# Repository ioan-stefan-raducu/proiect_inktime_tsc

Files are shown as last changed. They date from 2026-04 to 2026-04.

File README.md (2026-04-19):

# Proiect TSC 2026 - InkTime

Răducu Ioan Ștefan 335CA

## Descriere proiect
InkTime este un dispozitiv open source de tip smartwatch construit în cadrul clasei de proiectare hardware din UNSTPB. Device-ul are integrat un MCU nRF52840, senzori IMU și un display E-paper într-o carcasă compactă. Designul consideră aspectele legate de consum minim de energie și optimizarea PCB-ului pentru producție.

## Schema bloc
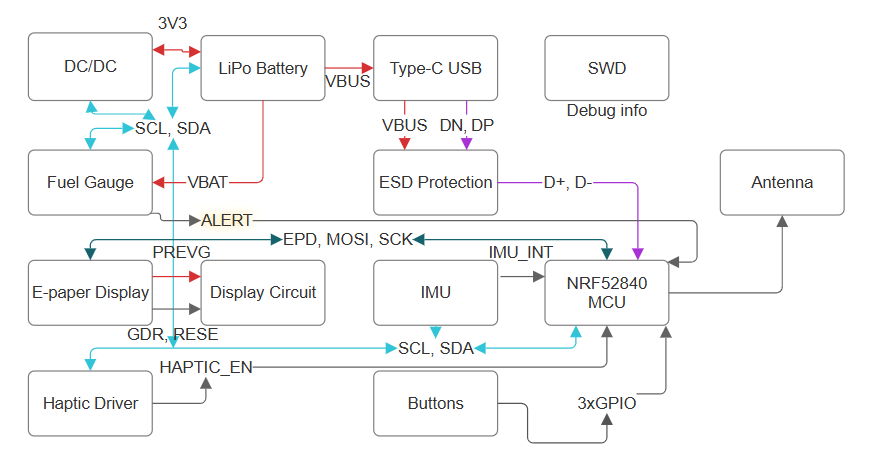
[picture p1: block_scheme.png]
schema bloc


Se pot vedea în schema bloc componentele conectate prin săgeți. Săgețile au următoarele semnificații:
- **roșu** - trasee de putere
- **albastru deschis** - conexiuni I2C
- **albastru închis** - conexiuni SPI
- **mov** - trasee diferențiale
- **gri** - conexiuni GPIO sau fără a aparține categoriilor de mai sus

## Bill of Materials

| Componentă / Valoare | Cant. | Capsulă | Producător / Part Number | Sursă Achiziție (JLC/Mouser) | Datasheet |
| :--- | :---: | :--- | :--- | :--- | :--- |
| **nRF52840** | 1 | aQFN-73 | Nordic / nRF52840-QIAA | [Mouser Link](https://www.mouser.ro/c/?q=nRF52840) | [Datasheet](https://infocenter.nordicsemi.com/pdf/nRF52840_PS_v1.1.pdf) |
| **BMA423** | 1 | 12-pin LGA | Bosch / BMA423 | [Mouser Link](https://www.mouser.co.uk/ProductDetail/Bosch-Sensortec/BMA423?qs=HXFqYaX1Q2xC%252BSgeGoX3mg%3D%3D) | [Datasheet](https://www.bosch-sensortec.com/media/boschsensortec/downloads/datasheets/bst-bma423-ds004.pdf) |
| **BQ25180YBGR** | 1 | BGA-8 | TI / BQ25180YBGR | [Mouser Link](https://www.mouser.co.uk/ProductDetail/Texas-Instruments/BQ25180YBGR?qs=doiCPypUmgEWjAK%252BJAX6Tw%3D%3D) | [Datasheet](https://www.ti.com/lit/ds/symlink/bq25180.pdf) |
| **MAX17048G+T10** | 1 | TDFN-8 | Analog Devices / MAX17048 | [Mouser Link](https://www.mouser.ro/Search/Refine?Keyword=MAX17048G%2BT10) | [Datasheet](https://datasheets.maximintegrated.com/en/ds/MAX17048-MAX17049.pdf) |
| **DRV2605YZFR** | 1 | BGA-9 | TI / DRV2605YZFR | [Mouser Link](https://www.mouser.ro/Search/Refine?Keyword=DRV2605YZFR) | [Datasheet](https://www.ti.com/lit/ds/symlink/drv2605.pdf) |
| **RT6160AWSC** | 1 | WLCSP-15 | Richtek / RT6160AWSC | [Mouser Link](https://www.mouser.co.uk/ProductDetail/Richtek/RT6160AWSC?qs=amGC7iS6iy%2FLd9PSoixZXQ%3D%3D) | [Datasheet](https://www.richtek.com/assets/product_file/RT6160/DS6160-03.pdf) |
| **2450AT18B100E** | 1 | 3216 (1206) | Johanson / Antenă 2.45GHz | [Mouser Link](https://www.mouser.co.uk/ProductDetail/Johanson-Technology/2450AT18B100E?qs=yCnrNFeXz%252Bh5MFsFIXGZGA%3D%3D) | [Datasheet](https://www.johansontechnology.com/datasheets/2450AT18B100E/2450AT18B100E.pdf) |
| **744043680 (L4)** | 1 | 4.8x4.8mm | Wurth / 68µH Inductor | [JLC Part](https://jlcpcb.com/partdetail/Wurth_Elektronik-744043680/C167448) | [Datasheet](https://www.we-online.com/catalog/datasheet/744043680.pdf) |
| **FTC252012SR47** | 1 | 2520 (1008) | TDK / 0.47µH Inductor | [JLC Part (C5832368)](https://jlcpcb.com/partdetail/6763488-FTC252012SR47MBCA/C5832368) | [Datasheet](https://product.tdk.com/en/system/files/dam/doc/product/inductor/inductor/smd/catalog/inductor_commercial_power_ftc252012s_en.pdf) |
| **503480-2400** | 1 | FPC-24 | Molex / Conector EPD | [Mouser Link](https://www.mouser.co.uk/ProductDetail/Molex/503480-2400?qs=OAhjpuo3Vu7efIoxFh9AOw%3D%3D) | [Datasheet](https://www.molex.com/pdm_docs/sd/5034802400_sd.pdf) |
| **USB-C 16P** | 1 | SMT | Kinghelm / KH-TYPE-C-16P | [JLC Part](https://jlcpcb.com/partdetail/Kinghelm-KH_TYPE_C_16P/C5186522) | [Datasheet](https://datasheet.lcsc.com/lcsc/2112151030_Kinghelm-KH-TYPE-C-16P_C2930266.pdf) |
| **EVP-AKE31A** | 3 | SMT (Buton) | Panasonic / Tactile SW | [Mouser Link](https://www.mouser.ro/Search/Refine?Keyword=EVP-AKE31A) | [Datasheet](https://industrial.panasonic.com/ww/products/pt/tactile-sw/models/EVPAKE31A) |
| **USBLC6-2SC6Y** | 1 | SOT-23-6 | ST / Protecție ESD | [JLC Part](https://jlcpcb.com/partdetail/STMicroelectronics-USBLC6_2SC6Y/C7519) | [Datasheet](https://www.st.com/resource/en/datasheet/usblc6-2.pdf) |
| **MBR0530** | 3 | SOD-123 | ON Semi / Schottky 0.5A | [JLC Part](https://jlcpcb.com/partdetail/onsemi-MBR0530T1G/C2131) | [Datasheet](https://www.onsemi.com/pdf/datasheet/mbr0530t1-d.pdf) |
| **SI1308EDL** | 1 | SC-70-3 | Vishay / N-Ch MOSFET | [Mouser Link](https://www.mouser.ro/Search/Refine?Keyword=SI1308EDL) | [Datasheet](https://www.vishay.com/docs/72013/si1308edl.pdf) |
| **DMG2305UX-7** | 1 | SOT-23 | Diodes Inc / P-Ch MOSFET | [JLC Part](https://jlcpcb.com/partdetail/Diodes_Incorporated-DMG2305UX_7/C128526) | [Datasheet](https://www.diodes.com/assets/Datasheets/DMG2305UX.pdf) |

### Rezistente si condensatoare

| Valoare | Cant. | Capsulă | Tip | JLC |
| :--- | :---: | :--- | :--- | :--- |
| **1uF / 50V** | 10 | 0402 | Condensator (EPD) | [C52923](https://jlcpcb.com/partdetail/Samsung_Electro_Mechanics-CL05A105KB5NQNC/C52923) |
| **10uF** | 4 | 0402 | Condensator | [C15525](https://jlcpcb.com/partdetail/Samsung_Electro_Mechanics-CL05A106MQ5NUNC/C15525) |
| **100nF** | 5 | 0201 | Condensator | [C1619](https://jlcpcb.com/partdetail/Murata_Electronics-GRM033R61A104KE84D/C1619) |
| **10K** | 6 | 0201 | Rezistență | [C25744](https://jlcpcb.com/partdetail/Yageo-RC0201JR_0710KL/C25744) |
| **5.1K (5K1)** | 2 | 0201 | Rezistență (USB CC) | [C25785](https://jlcpcb.com/partdetail/Yageo-RC0201JR_075K1L/C25785) |
| **3.3K (3K3)** | 2 | 0201 | Rezistență | [C25891](https://jlcpcb.com/partdetail/Yageo-RC0201JR_073K3L/C25891) |

## Funcționalități hardware

Pentru următoarele funcționalități hardware se vor folosi numele circuitelor așa cum sunt reprezentate în schematic. La conectarea cu alte circuite se vor menționa circuitele cu semnalele puse în paranteză, lângă menționarea lor.

### LiPo Battery
Circuitul LiPo battery este conectorul către baterie. El este amplasat aproape de circuitul **DC/DC (VREG, 3V3)** și **Fuel Gauge (3V3, VBAT)**, formând un ansamblu. Acest ansamblu este amplasat lângă **E-Paper Connector** și **USB Connector (VBUS)** pentru a izola zonele care se ocupă cu traseele de putere sau au putere mare de restul componentelor, pentru a evita interferențele. Este conectat la microcontroler prin protocolul I2C.

### Fuel Gauge
Circuitul Fuel Gauge se ocupă cu măsurarea nivelului bateriei și alertarea microprocesorului când bateria este descărcată. El este conectat la microcontroler prin protocolul I2C și semnalul **ALERT** (probabil folosit ca întrerupere).

### DC/DC
Circuitul DC/DC este adaptorul de tensiune al PCB-ului. El trimite semnale de putere folosind PWM pentru a regla tensiunea. Este conectat la procesor prin protocolul I2C.

### E-Paper Connector
Circuitul E-Paper Connector este conexiunea la ecranul E-Paper. El este conectat la microcontroler prin protocolul SPI. Semnalele care sunt conectate la microcontroler sunt **EPD_BUSY, EPD_RST, EPD_DC, EPD_CS, SCK și MOSI**. El este conectat și la circuitul **E-Paper Drive Circuit** prin PREVGH, PREVGL și 3V3.

### E-Paper Drive Circuit
Circuitul E-Paper Drive "crește” semnalul pentru modelarea cernelii pentru ecranul E-Paper. El este plasat direct lângă **E-Paper Display Connector** datorită semnalului puternic de putere (până la 50V) pe care îl transmite ecranului. Astfel, ansamblul de putere menționat mai devreme, conectorul E-Paper și acest circuit sunt puse apropiat pentru a nu interfera cu restul PCB-ului.

### USB-C Connector
Circuitul USB-C Connector reprezintă mufa USB. Este conectat la ansamblul de putere (VBUS) și la circuitul **ESD Protection (VBUS, DN, DP)**. Deși în designul PCB-ului DN și DP ar trebui să fie trasee diferențiale, ele nu sunt. Am luat această decizie datorită poziției apropiate a USB-C Connector față de circuitul ESD Protection. El este conectat la microcontroler prin semnalul VBUS și indirect, prin ESD Protection, prin semnalele diferențiale D+ și D-.

### ESD Protection
Circuitul ESD Protection reprezintă protecția mufei USB-C în cazul descărcărilor statice. El este conectat la **USB-C Connector (VBUS, DN, DP)** și la microcontroler (D+, D- trasee diferențiale). În designul PCB-ului, semnalele D+ și D- au aceeași lungime.

### SWD
Circuitul SWD este folosit pentru debugging și este conectat la semnalele importante (**RESET, 3V3 și GND**). Poate fi conectat la JTAG.

### Haptic Driver
Circuitul Haptic Driver este cel responsabil de vibrația ceasului. El este conectat la microcontroler prin protocolul I2C și semnalul **HAPTIC_EN**. În PCB, el este situat la distanță de IMU pentru a nu interfera cu acesta în momentul în care vibrează.

### IMU
Circuitul IMU măsoară accelerația și direcția ceasului pentru a determina câți pași a făcut utilizatorul. El este amplasat departe de Haptic Driver pentru motivul menționat mai sus și spre centrul ceasului pentru a măsura cât mai precis pașii (mișcarea ceasului pe mână poate afecta măsurătorile). El este conectat la microcontroler prin I2C și semnalele **IMUINT1 și IMUINT2** (întreruperi ce pot fi setate).

## Descrierea conexiunilor microcontrolerului nRF52840

* **P$AD22 (SWO)** - conexiune cu TP_SWO pentru debug.
* **P$AC13 (RESET)** - conexiune cu TP_RESET și SWD pentru resetarea componentei.
* **P$AD12 (EPD_BUSY)** - conexiune cu E-Paper Display (EPD_BUSY). Indică dacă ecranul este ocupat cu afișarea sau nu.
* **P$AD10 (EPD_DC)** - conexiune cu E-Paper Display (EPD_DC - Data/Command). Descrie dacă bitul trimis este pentru date (pixeli) sau o comandă.
* **P$K2 (EPD_CS)** - conexiune cu E-Paper Display (EPD_CS - Chip Select) pentru protocolul SPI.
* **P$AD12 (EPD_RST)** - conexiune cu E-Paper Display (EPD_RST) pentru resetare.
* **P$AC9 (P0.14)** - GPIO buton din mijloc.
* **P$AD8 (P0.13)** - GPIO buton din dreapta.
* **P$W24 (P1.02)** - GPIO buton din stânga.
* **P$AD6 (D+)** - traseu diferențial pozitiv către ESD Protection.
* **P$AD4 (D-)** - traseu diferențial negativ către ESD Protection.
* **P$AD2 (VBUS)** - conexiune cu semnalul VBUS al USB-C Connector.
* **P$U1 (HAPTIC_EN)** - conexiune cu Haptic Driver pentru enable/disable.
* **P$T2 (PMIC_INT)** - conexiune întrerupere cu circuitul bateriei (LiPo Battery).
* **P$P2 (IMU_INT2)** - conexiune întrerupere cu IMU.
* **P$M2 (SCL)** - conexiune I2C între restul componentelor care folosesc acest protocol.
* **P$N1 (IMU_INT1)** - conexiune întrerupere cu IMU.
* **P$L1 (SDA)** - conexiune I2C cu restul componentelor care folosesc acest protocol.
* **P$F2 și P$D2** - conexiune cu ceasul de 32 kHz.
* **P$A12 (SCK)** - conexiune clock cu ecranul pentru protocolul SPI.
* **P$P13 (MOSI)** - MOSI pentru conexiunea SPI (cu ecranul).
* **P$A23 și P$A24** - conexiune cu ceasul de 32 MHz.
* **P$J24 (ALERT)** - conexiune cu alerta circuitului Fuel Gauge.
* **P$Y23 (P1.01)** - conexiune care conduce E-Paper Drive Circuit pentru a afișa cerneala pe ecran.
* **P$AA24 (SWDCLK)** - conexiune pentru SWD, cu scopul de debug al ceasului.
* **P$AC24 (SWDIO)** - conexiune SWD input/output.
* **P$H23, P$F23** - conexiune pentru transmiterea wireless prin antenă.

## Aprobarea erorilor și alte detalii

În afara erorilor de overlap deja aprobate la început (în total 6 erori), restul erorilor pot fi explicate astfel:
* **6 erori** de Solid Polygon Shape, Overlap, la butoane, apărute de la sincronizarea inițială a schematicului cu PCB-ul.
* **11 erori** de Via-SMD sau SMD-Via, Overlap, pentru via-in-pad a pinilor de pe procesor.

### Detalii post-review
* Am mutat circuitul **IMU** mai sus pentru a aloca suficient spațiu pe PCB pentru un via mai gros de la pinul 3V3 la stratul POWER. Pre-review se folosea un via cu grosimea de 0.2mm direct sub componenta IMU.
* Pentru a rezolva al doilea via cu grosimea de 0.2mm pentru un traseu de putere de la pinul P$AD23 al nRF52840, am alocat suficient spațiu pentru a avea grosimea indicată.
* La rezolvarea greșelii din schematic în care am folosit componenta **NORDIC_NRF_3_CAPACITOR** în locul componentei **GRM011R60J152KE01L** pentru condensatori, a apărut problema overlap cu fire de 0.3mm din cauza footprint-ului 0201 pe care îl are obligatoriu noua componentă. Pentru a rezolva, am variat grosimea la 0.25mm. Personal aș fi păstrat componenta precedentă datorită footprint-ului 0402.
* Am mutat firul **P0.14** de pe bottom pentru a nu trece sub ceasul de 32 kHz al procesorului.
* În urma modificării schematicului circuitului Haptic Driver, pinul **SDA** era plasat în mijloc. Pentru a rezolva problema, am folosit via-in-pad. De asemenea, a fost nevoie să conectez pinul GND și am folosit via către stratul GND.

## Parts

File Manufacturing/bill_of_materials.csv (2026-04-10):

Qty | Value | Device | Package | Parts | Description | ARROW_PART_NUMBER | ARROW_PRICE-STOCK | AVAILABILITY | CHECK_PRICES | COPYRIGHT | DESCRIPTION | DIGI-KEY_PART_NUMBER_1 | DIGI-KEY_PART_NUMBER_2 | DIGI-KEY_PART_NUMBER_3 | HEIGHT | JLCPCB | MANUFACTURER_NAME | MANUFACTURER_PART_NUMBER | MF | MFR_NAME | MOUSER_PART_NUMBER | MOUSER_PRICE-STOCK | MP | PACKAGE | POPULARITY | PRICE | PROD_ID | PURCHASE-URL | SNAPEDA_LINK | TP_SIGNAL_NAME | VALUE
3 | 0 | CPF0201D7K68C1_CPF0201D7K68C1 | CPF0201D7K68C1_0201 | R2, R3, R4 | 7.68k 0201 Thin Film Surface Mount Fixed Resistor +/-0.5% 0.031W CPF0201D7K68C1
4 | 0.1uF | NORDIC_NRF_3_CAPACITOR_0201_L | NORDIC_NRF_3_RESC0201_L | C23, C27, C34, C42 | Generic chip capacitor
1 | 0.47 | CPF0201D7K68C1_CPF0201D7K68C1 | CPF0201D7K68C1_0201 | R1_EP_DR | 7.68k 0201 Thin Film Surface Mount Fixed Resistor +/-0.5% 0.031W CPF0201D7K68C1
5 | 100nF | NORDIC_NRF_3_CAPACITOR_0201_L | NORDIC_NRF_3_RESC0201_L | C5, C7, C8, C12, C19 | Generic chip capacitor
1 | 100pF | NORDIC_NRF_3_CAPACITOR_0201_L | NORDIC_NRF_3_RESC0201_L | C11 | Generic chip capacitor
6 | 10K | CPF0201D7K68C1_CPF0201D7K68C1 | CPF0201D7K68C1_0201 | R2_EP_DR, R5, R7, R8, R9, R_PWR_EPD | 7.68k 0201 Thin Film Surface Mount Fixed Resistor +/-0.5% 0.031W CPF0201D7K68C1
4 | 10uF | NORDIC_NRF_3_CAPACITOR_0402_L | NORDIC_NRF_3_RESC0402_L | C1-EP-DR, C1-EP-DR1, C24, C39 | Generic chip capacitor
1 | 10uH | NORDIC_NRF_2_INDUCTOR_0402_L | NORDIC_NRF_2_RESC0402_L | L2 | Generic chip inductor
4 | 12pF | NORDIC_NRF_3_CAPACITOR_0201_L | NORDIC_NRF_3_RESC0201_L | C1, C2, C17, C18 | Generic chip capacitor
1 | 15nH | NORDIC_NRF_2_INDUCTOR_0201_L | NORDIC_NRF_2_RESC0201_L | L3 | Generic chip inductor
2 | 1pF | NORDIC_NRF_3_CAPACITOR_0201_L | NORDIC_NRF_3_RESC0201_L | C3, C4 | Generic chip capacitor
7 | 1uF | NORDIC_NRF_3_CAPACITOR_0402_L | NORDIC_NRF_3_RESC0402_L | C15, C29, C30, C31, C32, C37, C38 | Generic chip capacitor
10 | 1uF/50V | NORDIC_NRF_3_CAPACITOR_0402_L | NORDIC_NRF_3_RESC0402_L | EPD_C1, EPD_C2, EPD_C5, EPD_C6, EPD_C7, EPD_C8, EPD_C9, EPD_C10, EPD_C11, EPD_C12 | Generic chip capacitor
1 | 2.2 | CPF0201D7K68C1_CPF0201D7K68C1 | CPF0201D7K68C1_0201 | R_TYPE_SEL | 7.68k 0201 Thin Film Surface Mount Fixed Resistor +/-0.5% 0.031W CPF0201D7K68C1
3 | 2025-10-22_07-23-44_LIBRARY_EVP-AKE31ASW_EVP-AKE31A_PAN | 2025-10-22_07-23-44_LIBRARY_EVP-AKE31ASW_EVP-AKE31A_PAN | 2025-10-22_07-23-44_LIBRARY_SW_EVP-AKE31A_PAN | SW_DN, SW_ENT, SW_UP |  |  |  |  |  | Copyright (C) 2025 Ultra Librarian. All rights reserved. |  | P123437TR-ND | P123437CT-ND | P123437DKR-ND |  |  | Panasonic | EVP-AKE31A
1 | 20V/4.2A/52mO/1.4W | ESP32_C6_LIBRARY_4_ESP32_WROVER_SPARKFUN-DISCRETESEMI_MOSFET_PCH-DMG2305UX-7 | ESP32_C6_LIBRARY_4_ESP32_C6_LIBRARY_4_ESP32_C6_LIBRARY_4_ESP32_C6_LIBRARY_4_ESP32_WROVER_SPARKFUN-DISCRETESEMI_SOT23-3 | Q1 | P-channel MOSFETs |  |  |  |  |  |  |  |  |  |  |  |  |  |  |  |  |  |  |  |  |  | TRAN-14388 |  |  |  | 20V/4.2A/52mO/1.4W
2 | 22uF | NORDIC_NRF_3_CAPACITOR_0402_L | NORDIC_NRF_3_RESC0402_L | C25, C33 | Generic chip capacitor
1 | 2450AT18B100E | 2450AT18B100E_2450AT18B100E | 2450AT18B100E_ANTC3216X140N | ANT1 | Antennas 2.45GHz ANTENNA | 2450AT18B100E | https://www.arrow.com/en/products/2450at18b100e/johanson-dielectrics?utm_currency=USD&region=nac |  |  |  | Antennas 2.45GHz ANTENNA |  |  |  | 1.4mm |  | JOHANSON TECHNOLOGY | 2450AT18B100E |  |  | 609-2450AT18B100E | https://www.mouser.co.uk/ProductDetail/Johanson-Technology/2450AT18B100E?qs=yCnrNFeXz%252Bh5MFsFIXGZGA%3D%3D
1 | 3.9nH | NORDIC_NRF_2_INDUCTOR_0201_L | NORDIC_NRF_2_RESC0201_L | L1 | Generic chip inductor
1 | 32.768kHz | NORDIC_NRF_1_XTAL_32KHZ | NORDIC_NRF_1_XTAL_3215_N | X2
1 | 32MHz | NORDIC_NRF_XTAL_32MHZ | NORDIC_NRF_BT-XTAL_2016_N | X1
2 | 3K3 | CPF0201D7K68C1_CPF0201D7K68C1 | CPF0201D7K68C1_0201 | R17, R18 | 7.68k 0201 Thin Film Surface Mount Fixed Resistor +/-0.5% 0.031W CPF0201D7K68C1
5 | 4.7uF | NORDIC_NRF_3_CAPACITOR_0402_L | NORDIC_NRF_3_RESC0402_L | C6, C14, C20, C21, C43 | Generic chip capacitor
1 | 47nF | NORDIC_NRF_3_CAPACITOR_0201_L | NORDIC_NRF_3_RESC0201_L | C16 | Generic chip capacitor
1 | 503480-2400 | 503480-2400_503480-2400 | 503480-2400_5034802400 | J1 | FFC & FPC Connectors 0.5mm FPC RA SMT Dual Contact 24Ckt |  |  |  |  |  | FFC & FPC Connectors 0.5mm FPC RA SMT Dual Contact 24Ckt |  |  |  | 1.87mm |  | Molex | 503480-2400 |  |  | 538-503480-2400 | https://www.mouser.co.uk/ProductDetail/Molex/503480-2400?qs=OAhjpuo3Vu7efIoxFh9AOw%3D%3D
2 | 5K1 | ERA-1AEB3401C_CPF0201D7K68C1 | ERA-1AEB3401C_0201 | R1_USB, R2_USB | 7.68k 0201 Thin Film Surface Mount Fixed Resistor +/-0.5% 0.031W CPF0201D7K68C1
1 | 68uH | ESP32_C6_LIBRARY_2_744043680IND_4828-WE-TPC_WRE | ESP32_C6_LIBRARY_2_IND_4828-WE-TPC_WRE | L4 |  |  |  |  |  | Copyright (C) 2024 Ultra Librarian. All rights reserved. |  |  |  |  |  |  |  | 744043680 |  | Wurth Electronics
1 | 820pF | NORDIC_NRF_3_CAPACITOR_0201_L | NORDIC_NRF_3_RESC0201_L | C9 | Generic chip capacitor
1 | BMA423 | BMA423_BMA423 | BMA423_BMA423 | IC3 | Accelerometers Triaxial low-g 12bit Acceleration Sensor | BMA423 | https://www.arrow.com/en/products/bma423/bosch |  |  |  | Accelerometers Triaxial low-g 12bit Acceleration Sensor |  |  |  | 1mm |  | BOSCH | BMA423 |  |  | 262-BMA423 | https://www.mouser.co.uk/ProductDetail/Bosch-Sensortec/BMA423?qs=HXFqYaX1Q2xC%252BSgeGoX3mg%3D%3D
1 | BQ25180YBGR | BQ25180YBGR_BQ25180YBGR | BQ25180YBGR_BGA8C40P2X4_100X155X50 | IC1 | Charger IC Lithium Ion/Polymer, Lithium Iron Phosphate 8-DSBGA (1.6x1.1) | BQ25180YBGR | https://www.arrow.com/en/products/bq25180ybgr/texas-instruments?utm_currency=USD&region=nac |  |  |  | Charger IC Lithium Ion/Polymer | Lithium Iron Phosphate 8-DSBGA (1.6x1.1) |  |  |  | 0.5mm |  | Texas Instruments | BQ25180YBGR |  |  | 595-BQ25180YBGR | https://www.mouser.co.uk/ProductDetail/Texas-Instruments/BQ25180YBGR?qs=doiCPypUmgEWjAK%252BJAX6Tw%3D%3D
1 | DRV2605YZFR | DRV2605YZFR_DRV2605YZFR | DRV2605YZFR_BGA9C50P3X3_144X144X62 | IC2 | Haptic Driver for ERM/LRA with Built-In Library and Smart Loop Architecture | DRV2605YZFR | https://www.arrow.com/en/products/drv2605yzfr/texas-instruments?region=nac |  |  |  | Haptic Driver for ERM/LRA with Built-In Library and Smart Loop Architecture |  |  |  | 0.625mm |  | Texas Instruments | DRV2605YZFR
1 | FTC252012SR47MBCA | MLP2016SR47MT0S1_FTC252012SR47MBCA | MLP2016SR47MT0S1_INDC2016X100N | L7 | SMD / SMT Inductors (Coils), L=0.47?H, L x W x T : |  |  |  |  |  | SMD / SMT Inductors (Coils) | L=0.47?H | L x W x T : |  |  |  | 1mm | https://jlcpcb.com/partdetail/6763488-FTC252012SR47MBCA/C5832368 | TDK | FTC252012SR47MBCA
14 | HECTOR_WATCH_1_TPTP20R | HECTOR_WATCH_1_TPTP20R | HECTOR_WATCH_1_TP20R | TP_3.3V, TP_3V3, TP_BAT_GND, TP_GND, TP_ON, TP_OP, TP_RESET\, TP_SCL, TP_SDA, TP_SWDCLK, TP_SWDIO, TP_SWO, TP_VBAT, TP_VREG | Test pad |  |  |  |  |  |  |  |  |  |  |  |  |  |  |  |  |  |  |  | 2
1 | JUMPER_SJ | ESP32_C6_LIBRARY_7_JUMPER_SJ | ESP32_C6_LIBRARY_7_JUMPER_SJ | SJ1 | SMD solder JUMPER |  |  |  |  |  |  |  |  |  |  |  |  |  |  |  |  |  |  |  | 3
1 | KH-TYPE-C-16P | KH-TYPE-C-16P_KH-TYPE-C-16P | KH-TYPE-C-16P_KINGHELM_KH-TYPE-C-16P | J4 | Check availability |  |  | Not in stock | https://www.snapeda.com/parts/KH-TYPE-C-16P/Kinghelm/view-part/?ref=eda |  |  |  |  |  |  |  |  |  | kinghelm |  |  |  | KH-TYPE-C-16P | None |  | None |  |  | https://www.snapeda.com/parts/KH-TYPE-C-16P/Kinghelm/view-part/?ref=snap
1 | MAX17048G+T10 | ESP32_C6_LIBRARY_MAX17048G+T10 | ESP32_C6_LIBRARY_SON50P200X200X80-9N | U3 | Check availability |  |  | In Stock | https://www.snapeda.com/parts/MAX17048G+T10/Analog+Devices/view-part/?ref=eda |  | 3µA 1-Cell/2-Cell Fuel Gauge with ModelGauge |  |  |  |  |  |  |  | Analog Devices |  |  |  | MAX17048G+T10 | TDFN-8 Maxim |  | None |  | https://www.snapeda.com/api/url_track_click_mouser/?unipart_id=329239&manufacturer=Analog Devices&part_name=MAX17048G+T10&search_term=None | https://www.snapeda.com/parts/MAX17048G+T10/Analog+Devices/view-part/?ref=snap
3 | MBR0530 | ESP32_C6_LIBRARY_5_MBR0530 | ESP32_C6_LIBRARY_5_SOD3716X135N | D3, D4, D5 | ON SEMICONDUCTOR - MBR0530 - DIODE, SCHOTTKY, 0.5A, 30V, SOD-123 |  |  | In Stock | https://www.snapeda.com/parts/MBR0530/Onsemi/view-part/?ref=eda |  | Diode Schottky 30 V 500mA Surface Mount SOD-123 |  |  |  |  |  |  |  | ON Semiconductor |  |  |  | MBR0530 | SOD-123-2 ON Semiconductor |  | None |  | https://www.snapeda.com/api/url_track_click_mouser/?unipart_id=179458&manufacturer=ON Semiconductor&part_name=MBR0530&search_term=None | https://www.snapeda.com/parts/MBR0530/Onsemi/view-part/?ref=snap
3 | N.C. | NORDIC_NRF_3_CAPACITOR_0201_L | NORDIC_NRF_3_RESC0201_L | C10, C13, C22 | Generic chip capacitor
1 | NRF52840_QF | NORDIC_NRF_4_NRF52840_QF | NORDIC_NRF_4_AQFN50P700X700X85_HS-74N | U1 | nRF52840
1 | RT6160AWSC | RT6160AWSC_RT6160AWSC | RT6160AWSC_BGA15C40P3X5_140X230X60 | IC9 | Buck-Boost Regulator Positive Output Step-Up/Step-Down I2C DC-DC Controller IC 15-WL-CSP (BSC) (1.4x2.3) |  |  |  |  |  | Buck-Boost Regulator Positive Output Step-Up/Step-Down I2C DC-DC Controller IC 15-WL-CSP (BSC) (1.4x2.3) |  |  |  | 0.6mm |  | RICHTEK | RT6160AWSC |  |  | 835-RT6160AWSC | https://www.mouser.co.uk/ProductDetail/Richtek/RT6160AWSC?qs=amGC7iS6iy%2FLd9PSoixZXQ%3D%3D
1 | SI1308EDL-T1-GE3 | ESP32_C6_LIBRARY_6_SI1308EDL-T1-GE3 | ESP32_C6_LIBRARY_6_SOT65P210X110-3N | Q3 | MOSFET N-Ch 30V 1.5A TrenchFET SC70 Vishay Si1308EDL-T1-GE3 N-channel MOSFET Transistor, 1.5 A, 30 V, 3-Pin SC-70 |  |  | In Stock | https://www.snapeda.com/parts/SI1308EDL-T1-GE3/Vishay+Siliconix/view-part/?ref=eda |  | Si1308EDL-T1-GE3 N-channel MOSFET Transistor | 1.5 A | 30 V | 3-Pin SC-70 | Siliconix / Vishay SI1308EDL-T1-GE3 |  |  |  |  |  |  |  | Vishay Siliconix |  |  |  | SI1308EDL-T1-GE3 | SOT-323 Vishay Semiconductor |  | None |  | https://www.snapeda.com/api/url_track_click_mouser/?unipart_id=274603&manufacturer=Vishay Siliconix&part_name=SI1308EDL-T1-GE3&search_term=None
1 | TC2030-IDC | TC2030-IDC_TC2030-IDC | TC2030-IDC_TC2030IDC | J2 | CABLE ADAPTER 6 POS |  |  |  |  |  | CABLE ADAPTER 6 POS |  |  |  | 19mm |  | Tag Connect | TC2030-IDC
1 | USBLC6-2SC6Y | ESP32_C6_LIBRARY_3_USBLC6-2SC6Y | ESP32_C6_LIBRARY_3_SOT95P280X145-6N | D2 | Low Cap. ESD Protection Auto SOT-23-6 STMicroelectronics USBLC6-2SC6Y, Dual Uni-Directional TVS Diode Array, 6-Pin SOT-23 |  |  | In Stock | https://www.snapeda.com/parts/USBLC6-2SC6Y/STMicroelectronics/view-part/?ref=eda |  | 17V Clamp 5A (8/20µs) Ipp Tvs Diode Surface Mount SOT-23-6 |  |  |  |  |  |  |  | STMicroelectronics |  |  |  | USBLC6-2SC6Y | SOT-23-6 STMicroelectronics |  | None |  |  | https://www.snapeda.com/parts/USBLC6-2SC6Y/STMicroelectronics/view-part/?ref=snap

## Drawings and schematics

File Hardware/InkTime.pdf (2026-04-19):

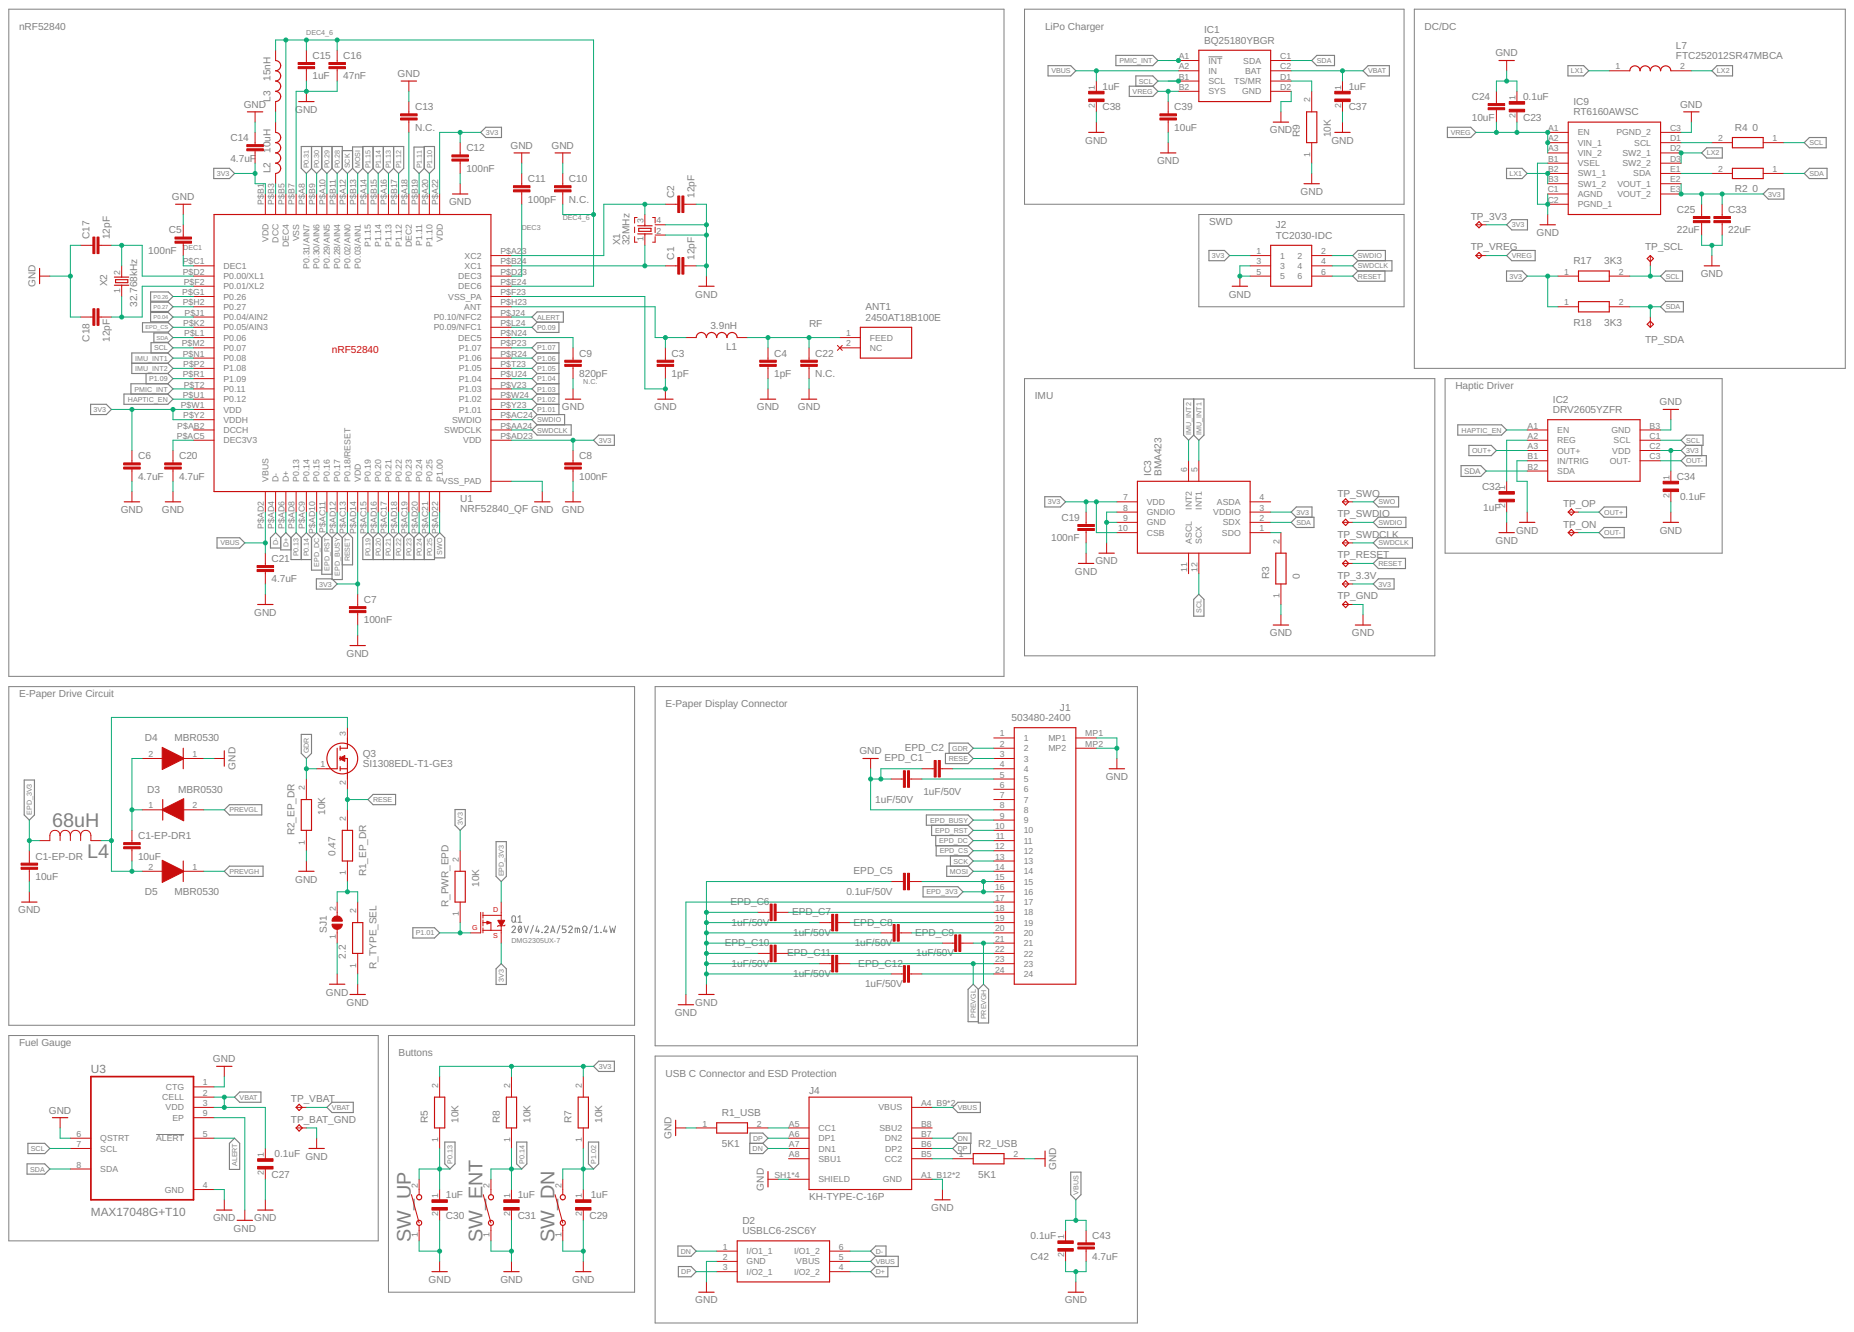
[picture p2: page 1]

10KGND GND GND GND GND

EPD_3V3 | 16

18
19
20

22
23
24

USB C Connector and ESD Protection

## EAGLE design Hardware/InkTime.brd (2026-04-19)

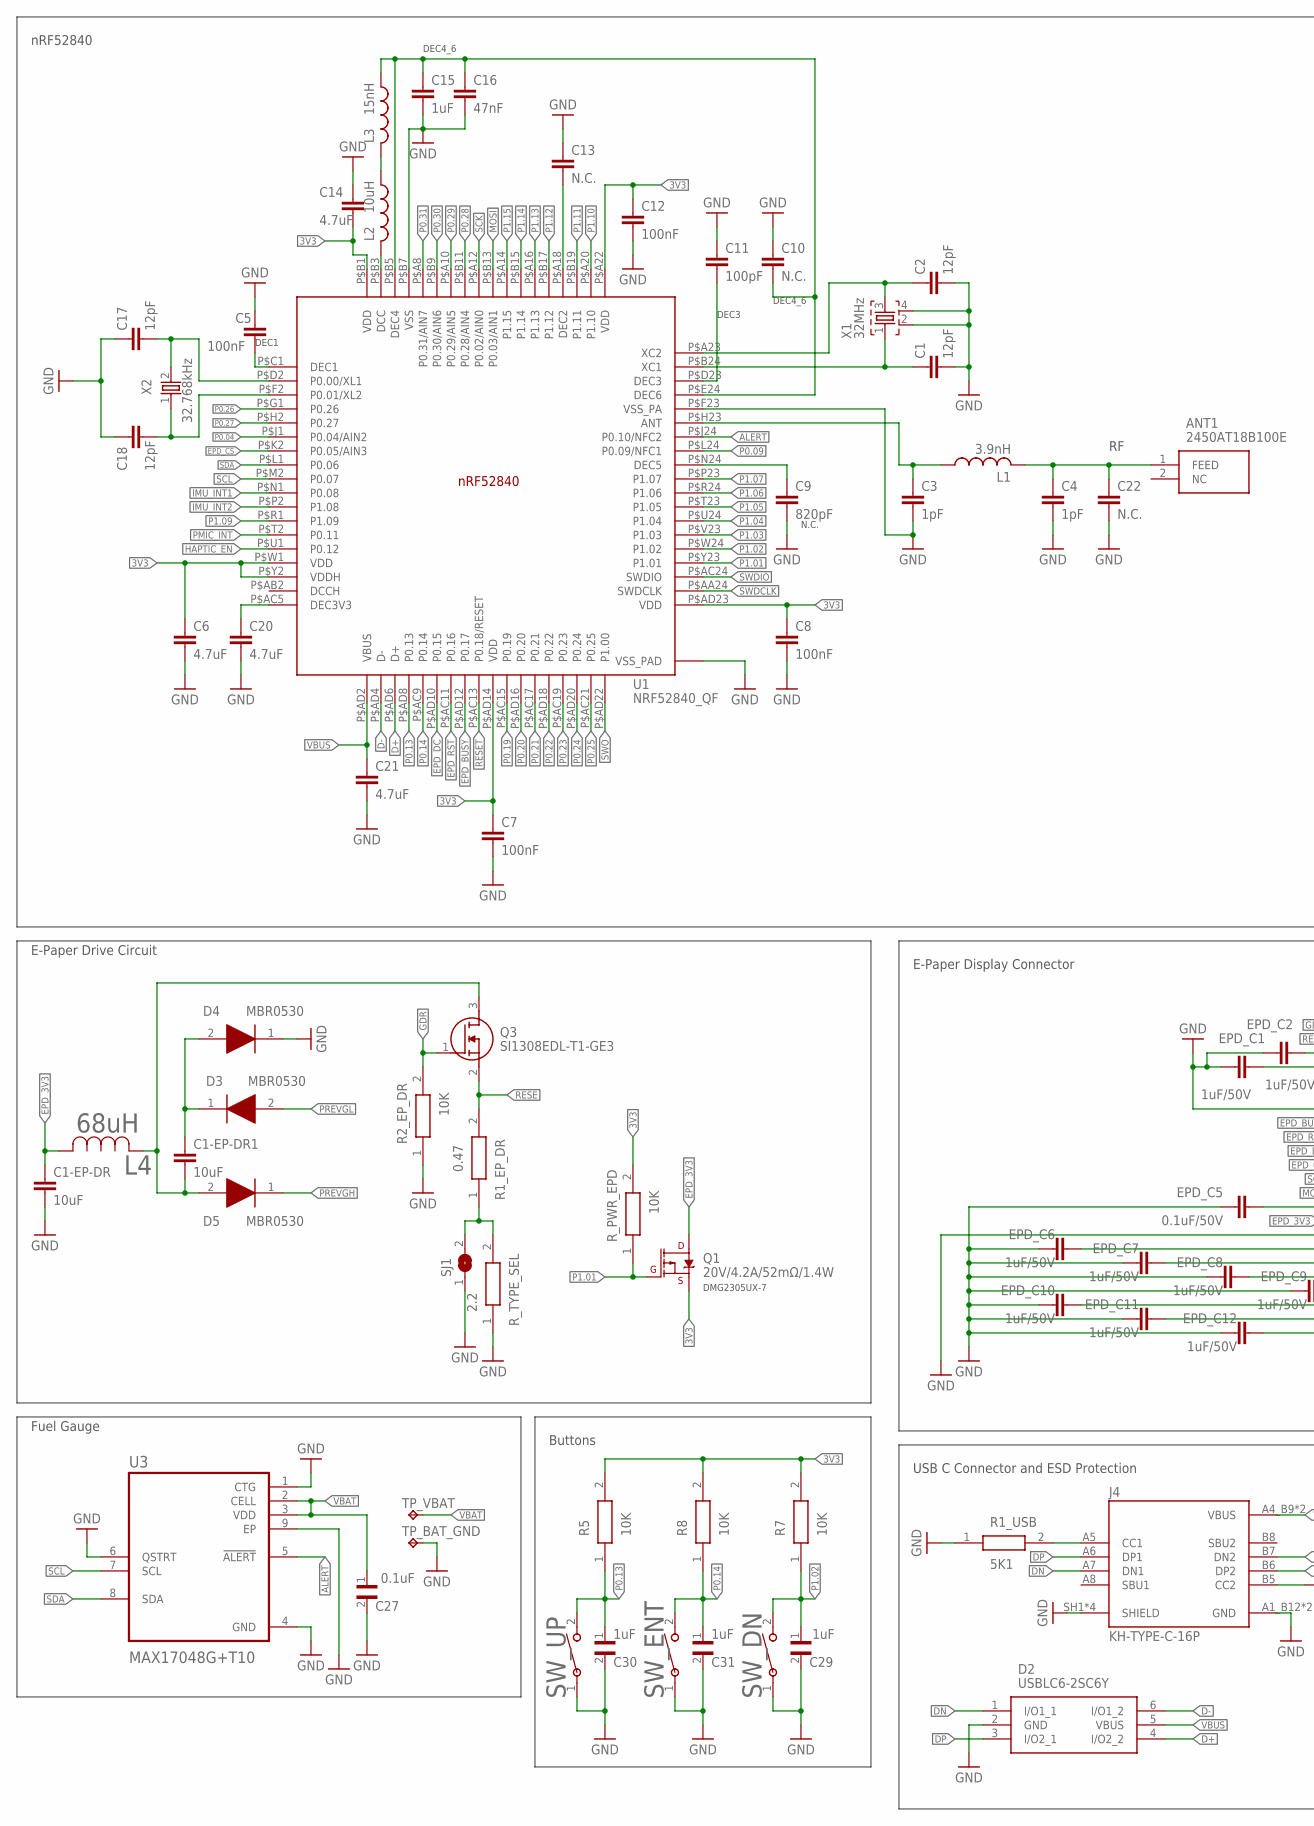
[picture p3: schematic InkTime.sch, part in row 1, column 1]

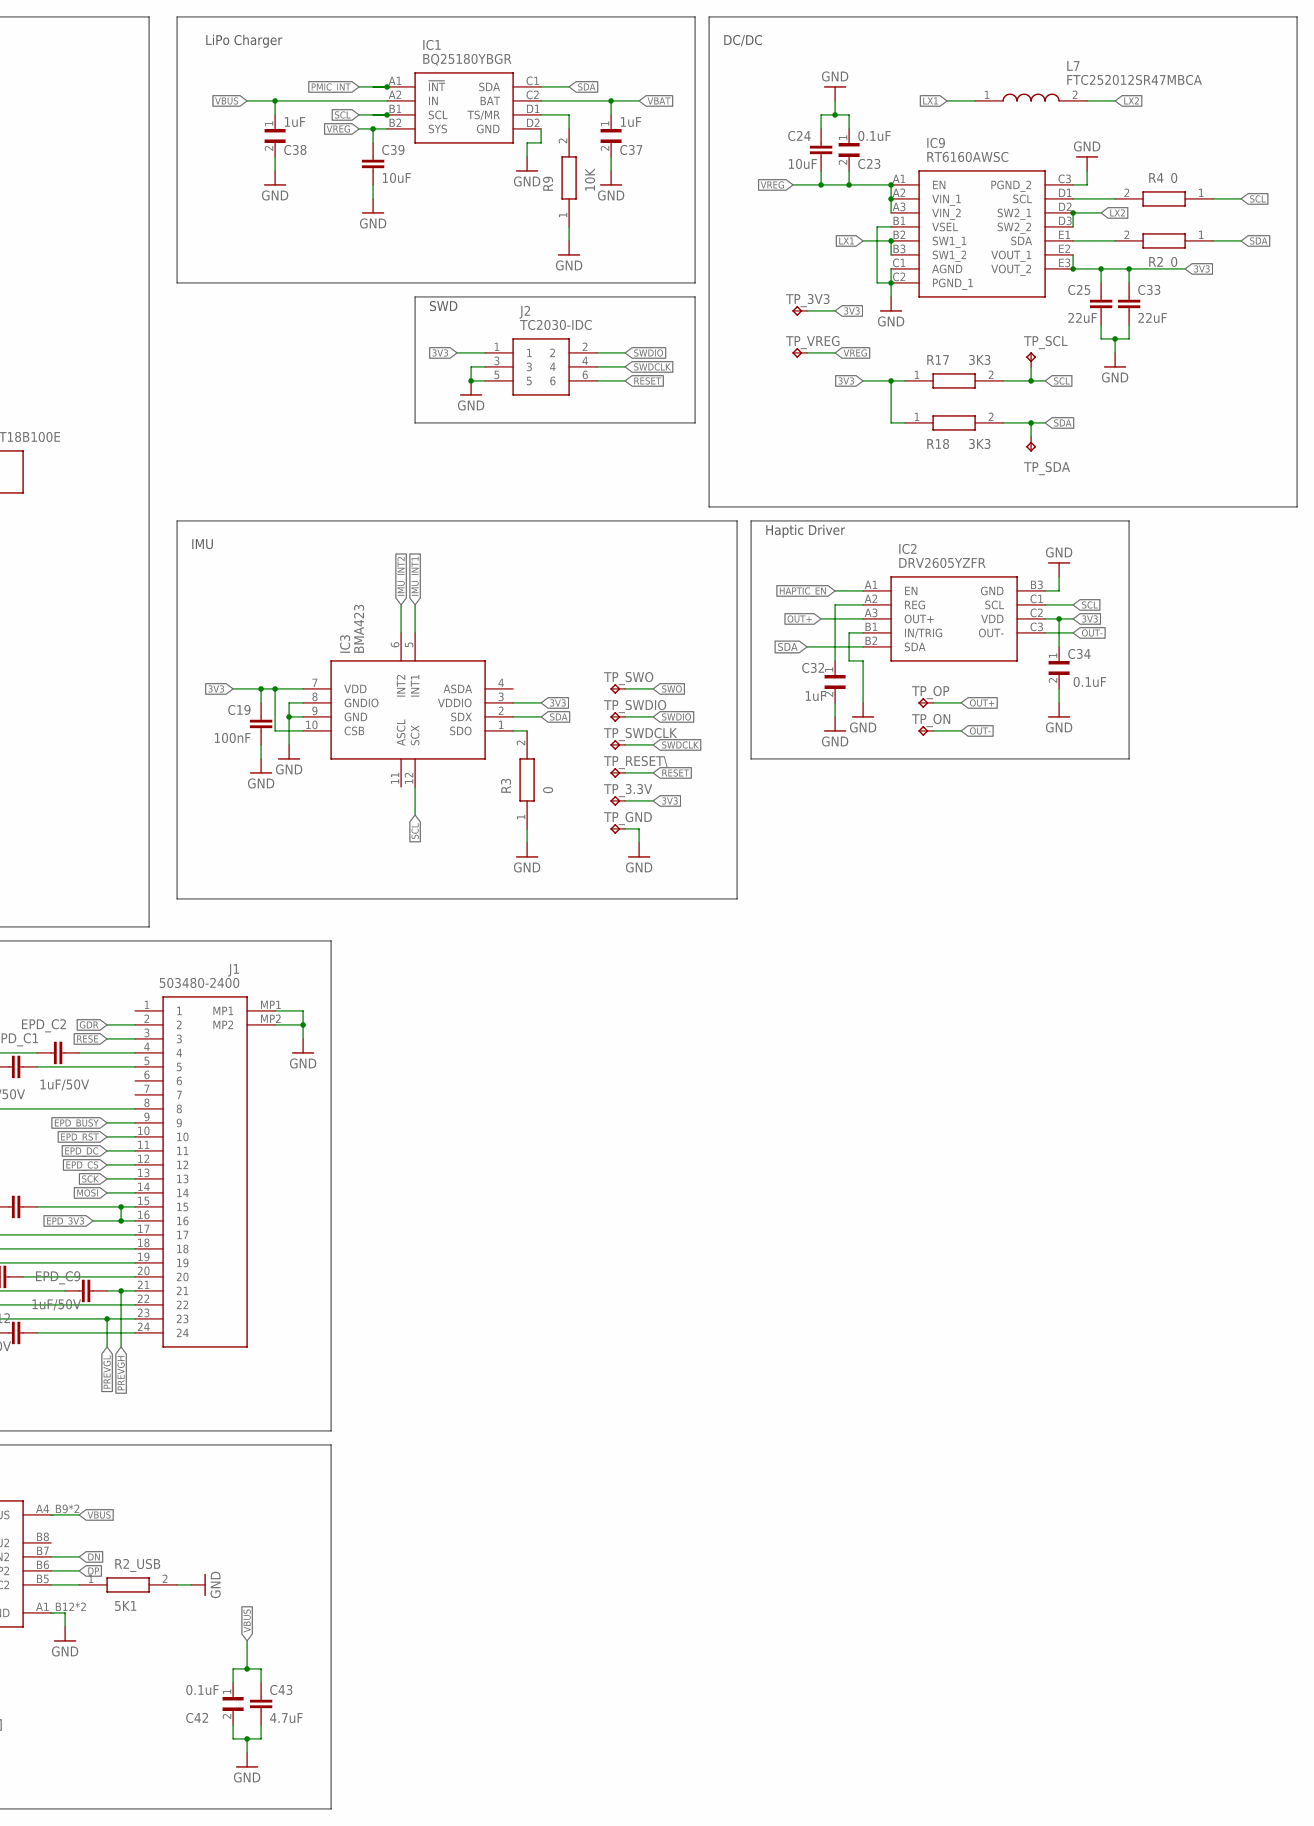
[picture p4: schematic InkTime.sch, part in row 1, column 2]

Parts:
ANT1: 2450AT18B100E; 2450AT18B100E_ANTC3216X140N
C1, C2, C17, C18: 12pF; NORDIC_NRF_3_RESC0201_L
C1-EP-DR, C1-EP-DR1, C24, C39: 10uF; NORDIC_NRF_3_RESC0402_L
C3, C4: 1pF; NORDIC_NRF_3_RESC0201_L
C5, C7, C8, C12, C19: 100nF; NORDIC_NRF_3_RESC0201_L
C6, C14, C20, C21, C43: 4.7uF; NORDIC_NRF_3_RESC0402_L
C9: 820pF; NORDIC_NRF_3_RESC0201_L
C10, C13, C22: N.C.; NORDIC_NRF_3_RESC0201_L
C11: 100pF; NORDIC_NRF_3_RESC0201_L
C15: 1uF; NORDIC_NRF_3_RESC0402_L
C16: 47nF; NORDIC_NRF_3_RESC0201_L
C23, C27, C34, C42: 0.1uF; GRM011R60J152KE01L_2_CAPC0201X13N
C25, C33: 22uF; NORDIC_NRF_3_RESC0402_L
C29, C30, C31, C32, C37, C38: 1uF; GRM011R60J152KE01L_2_CAPC0201X13N
D2: USBLC6-2SC6Y; ESP32_C6_LIBRARY_3_SOT95P280X145-6N
D3, D4, D5: MBR0530; ESP32_C6_LIBRARY_5_SOD3716X135N
EPD_C1, EPD_C2, EPD_C6, EPD_C7, EPD_C8, EPD_C9, EPD_C10, EPD_C11, EPD_C12: 1uF/50V; NORDIC_NRF_3_RESC0402_L
EPD_C5: 0.1uF/50V; NORDIC_NRF_3_RESC0201_L
IC1: BQ25180YBGR; BQ25180YBGR_BGA8C40P2X4_100X155X50
IC2: DRV2605YZFR; DRV2605YZFR_BGA9C50P3X3_144X144X62
IC3: BMA423; BMA423_BMA423
IC9: RT6160AWSC; RT6160AWSC_BGA15C40P3X5_140X230X60
J1: 503480-2400; 503480-2400_5034802400
J2: TC2030-IDC; TC2030-IDC_TC2030IDC
J4: KH-TYPE-C-16P; KH-TYPE-C-16P_KINGHELM_KH-TYPE-C-16P
L1: 3.9nH; NORDIC_NRF_2_RESC0201_L
L2: 10uH; NORDIC_NRF_2_RESC0402_L
L3: 15nH; NORDIC_NRF_2_RESC0201_L
L4: 68uH; ESP32_C6_LIBRARY_2_IND_4828-WE-TPC_WRE
L7: FTC252012SR47MBCA; MLP2016SR47MT0S1_INDC2016X100N
Q1: 20V/4.2A/52mΩ/1.4W; ESP32_C6_LIBRARY_4_ESP32_C6_LIBRARY_4_ESP32_C6_LIBRARY_4_ES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
Q3: SI1308EDL-T1-GE3; ESP32_C6_LIBRARY_6_SOT65P210X110-3N
R1_EP_DR: 0.47; CPF0201D7K68C1_0201
R1_USB, R2_USB: 5K1; ERA-1AEB3401C_0201
R2, R3, R4: 0; CPF0201D7K68C1_0201
R2_EP_DR, R5, R7, R8, R9: 10K; CPF0201D7K68C1_0201
R17, R18: 3K3; CPF0201D7K68C1_0201
R_PWR_EPD: 10K; CPF0201D7K68C1_0201
R_TYPE_SEL: 2.2; CPF0201D7K68C1_0201
SJ1: JUMPER_SJ; ESP32_C6_LIBRARY_7_JUMPER_SJ
SW_DN: 2025-10-22_07-23-44_LIBRARY_EVP-AKE31ASW_EVP-AKE3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; 2025-10-22_07-23-44_LIBRARY_SW_EVP-AKE31A_PAN
SW_ENT: 2025-10-22_07-23-44_LIBRARY_EVP-AKE31ASW_EVP-AKE3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; 2025-10-22_07-23-44_LIBRARY_SW_EVP-AKE31A_PAN
SW_UP: 2025-10-22_07-23-44_LIBRARY_EVP-AKE31ASW_EVP-AKE3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; 2025-10-22_07-23-44_LIBRARY_SW_EVP-AKE31A_PAN
TP_3.3V, TP_3V3: HECTOR_WATCH_1_TPTP20R; HECTOR_WATCH_1_TP20R
TP_BAT_GND: HECTOR_WATCH_1_TPTP20R; HECTOR_WATCH_1_TP20R
TP_GND: HECTOR_WATCH_1_TPTP20R; HECTOR_WATCH_1_TP20R
TP_ON: HECTOR_WATCH_1_TPTP20R; HECTOR_WATCH_1_TP20R
TP_OP: HECTOR_WATCH_1_TPTP20R; HECTOR_WATCH_1_TP20R
TP_RESET\: HECTOR_WATCH_1_TPTP20R; HECTOR_WATCH_1_TP20R
TP_SCL: HECTOR_WATCH_1_TPTP20R; HECTOR_WATCH_1_TP20R
TP_SDA: HECTOR_WATCH_1_TPTP20R; HECTOR_WATCH_1_TP20R
TP_SWDCLK: HECTOR_WATCH_1_TPTP20R; HECTOR_WATCH_1_TP20R
TP_SWDIO: HECTOR_WATCH_1_TPTP20R; HECTOR_WATCH_1_TP20R
TP_SWO: HECTOR_WATCH_1_TPTP20R; HECTOR_WATCH_1_TP20R
TP_VBAT: HECTOR_WATCH_1_TPTP20R; HECTOR_WATCH_1_TP20R
TP_VREG: HECTOR_WATCH_1_TPTP20R; HECTOR_WATCH_1_TP20R
U1: NRF52840_QF; NORDIC_NRF_4_AQFN50P700X700X85_HS-74N
U3: MAX17048G+T10; ESP32_C6_LIBRARY_SON50P200X200X80-9N
X1: 32MHz; NORDIC_NRF_BT-XTAL_2016_N
X2: 32.768kHz; NORDIC_NRF_1_XTAL_3215_N

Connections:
3V3: C6.1, C7.1, C8.1, C12.1, C14.2, C19.1, C25.1, C33.1, C34.1, IC2.C2 (VDD), IC3.3 (VDDIO), IC3.7 (VDD), IC3.10 (CSB), IC9.E2 (VOUT_1), IC9.E3 (VOUT_2), J2.1, Q1.2 (S), R5.2, R7.2, R8.2, R17.1, R18.1, R_PWR_EPD.2, TP_3.3V.TP, TP_3V3.TP, U1.P$A22 (VDD), U1.P$AD14 (VDD), U1.P$AD23 (VDD), U1.P$B1 (VDD), U1.P$W1 (VDD), U1.P$Y2 (VDDH)
ALERT: U1.P$J24 (P0.10/NFC2), U3.5 (!ALERT)
D+: D2.4 (I/O2_2), U1.P$AD6 (D+)
D-: D2.6 (I/O1_2), U1.P$AD4 (D-)
DN: D2.1 (I/O1_1), J4.A7 (DN1), J4.B7 (DN2)
DP: D2.3 (I/O2_1), J4.A6 (DP1), J4.B6 (DP2)
EPD_3V3: C1-EP-DR.1, EPD_C5.1, J1.15, J1.16, L4.2, Q1.3 (D)
EPD_BUSY: J1.9, U1.P$AD12 (P0.17)
EPD_CS: J1.12, U1.P$K2 (P0.05/AIN3)
EPD_DC: J1.11, U1.P$AD10 (P0.15)
EPD_RST: J1.10, U1.P$AC11 (P0.16)
GDR: J1.2, Q3.1 (G), R2_EP_DR.2
GND: C1.2, C1-EP-DR.2, C2.2, C3.2, C4.2, C5.1, C6.2, C7.2, C8.2, C9.2, C10.1, C11.1, C12.2, C13.1, C14.1, C15.2, C16.2, C17.1, C18.1, C19.2, C20.2, C21.2, C22.2, C23.1, C24.1, C25.2, C27.2, C29.2, C30.2, C31.2, C32.2, C33.2, C34.2, C37.2, C38.2, C39.2, C42.2, C43.2, D2.2 (GND), D4.1 (K), EPD_C1.2, EPD_C2.2, EPD_C5.2, EPD_C6.2, EPD_C7.2, EPD_C8.2, EPD_C9.2, EPD_C10.2, EPD_C11.2, EPD_C12.2, IC1.D2 (GND), IC2.B1 (IN/TRIG), IC2.B3 (GND), IC3.8 (GNDIO), IC3.9 (GND), IC9.B1 (VSEL), IC9.C1 (AGND), IC9.C2 (PGND_1), IC9.C3 (PGND_2), J1.8, J1.17, J1.MP1, J1.MP2, J2.3, J2.5, J4.A1_B12 (GND), J4.A12_B1 (GND), J4.SH1 (SHIELD), J4.SH2 (SHIELD), J4.SH3 (SHIELD), J4.SH4 (SHIELD), R1_USB.1, R2_EP_DR.1, R2_USB.2, R3.1, R9.1, R_TYPE_SEL.1, SJ1.1, SW_DN.1, SW_ENT.1, SW_UP.1, TP_BAT_GND.TP, TP_GND.TP, U1.P$74 (VSS_PAD), U1.P$75 (VSS_PAD), U1.P$76 (VSS_PAD), U1.P$77 (VSS_PAD), U1.P$78 (VSS_PAD), U1.P$79 (VSS_PAD), U1.P$80 (VSS_PAD), U1.P$81 (VSS_PAD), U1.P$82 (VSS_PAD), U1.P$83 (VSS_PAD), U1.P$84 (VSS_PAD), U1.P$85 (VSS_PAD), U1.P$86 (VSS_PAD), U1.P$87 (VSS_PAD), U1.P$88 (VSS_PAD), U1.P$89 (VSS_PAD), U1.P$90 (VSS_PAD), U1.P$B7 (VSS), U1.P$F23 (VSS_PA), U3.1 (CTG), U3.4 (GND), U3.6 (QSTRT), U3.9 (EP), X1.2, X1.4
HAPTIC_EN: IC2.A1 (EN), U1.P$U1 (P0.12)
IMU_INT1: IC3.5 (INT1), U1.P$N1 (P0.08)
IMU_INT2: IC3.6 (INT2), U1.P$P2 (P1.08)
LX1: IC9.B2 (SW1_1), IC9.B3 (SW1_2), L7.1
LX2: IC9.D2 (SW2_1), IC9.D3 (SW2_2), L7.2
MOSI: J1.14, U1.P$B13 (P0.03/AIN1)
unnamed: IC1.D1 (TS/MR), R9.2
unnamed: J4.A5 (CC1), R1_USB.2
unnamed: C1-EP-DR1.2, D5.2 (A), L4.1, Q3.3 (D)
unnamed: IC3.1 (SDO), R3.2
unnamed: EPD_C2.1, J1.4
unnamed: EPD_C1.1, J1.5
unnamed: EPD_C12.1, J1.24
unnamed: IC9.D1 (SCL), R4.2
unnamed: EPD_C10.1, J1.22
unnamed: IC9.E1 (SDA), R2.2
unnamed: EPD_C8.1, J1.20
unnamed: EPD_C7.1, J1.19
unnamed: EPD_C6.1, J1.18
unnamed: C9.1, U1.P$N24 (DEC5)
unnamed: C3.1, L1.1, U1.P$H23 (ANT)
unnamed: ANT1.1 (FEED), C4.1, C22.1, L1.2
unnamed: C2.1, U1.P$A23 (XC2), X1.3
unnamed: C1.1, U1.P$B24 (XC1), X1.1
unnamed: C11.2, U1.P$D23 (DEC3)
unnamed: C13.2, U1.P$A18 (DEC2)
unnamed: L2.2, U1.P$B3 (DCC)
unnamed: L2.1, L3.2
unnamed: C10.2, C15.1, C16.1, L3.1, U1.P$B5 (DEC4), U1.P$E24 (DEC6)
unnamed: C5.2, U1.P$C1 (DEC1)
unnamed: C17.2, U1.P$D2 (P0.00/XL1), X2.2
unnamed: C18.2, U1.P$F2 (P0.01/XL2), X2.1
unnamed: C1-EP-DR1.1, D3.1 (K), D4.2 (A)
unnamed: J4.B5 (CC2), R2_USB.1
unnamed: C32.1, IC2.A2 (REG)
unnamed: R1_EP_DR.1, R_TYPE_SEL.2, SJ1.2
OUT+: IC2.A3 (OUT+), TP_OP.TP
OUT-: IC2.C3 (OUT-), TP_ON.TP
P0.04: U1.P$J1 (P0.04/AIN2)
P0.09: U1.P$L24 (P0.09/NFC1)
P0.13: C30.1, R5.1, SW_UP.2, U1.P$AD8 (P0.13)
P0.14: C31.1, R8.1, SW_ENT.2, U1.P$AC9 (P0.14)
P0.19: U1.P$AC15 (P0.19)
P0.20: U1.P$AD16 (P0.20)
P0.21: U1.P$AC17 (P0.21)
P0.22: U1.P$AD18 (P0.22)
P0.23: U1.P$AC19 (P0.23)
P0.24: U1.P$AD20 (P0.24)
P0.25: U1.P$AC21 (P0.25)
P0.26: U1.P$G1 (P0.26)
P0.27: U1.P$H2 (P0.27)
P0.28: U1.P$B11 (P0.28/AIN4)
P0.29: U1.P$A10 (P0.29/AIN5)
P0.30: U1.P$B9 (P0.30/AIN6)
P0.31: U1.P$A8 (P0.31/AIN7)
P1.01: Q1.1 (G), R_PWR_EPD.1, U1.P$Y23 (P1.01)
P1.02: C29.1, R7.1, SW_DN.2, U1.P$W24 (P1.02)
P1.03: U1.P$V23 (P1.03)
P1.04: U1.P$U24 (P1.04)
P1.05: U1.P$T23 (P1.05)
P1.06: U1.P$R24 (P1.06)
P1.07: U1.P$P23 (P1.07)
P1.09: U1.P$R1 (P1.09)
P1.10: U1.P$A20 (P1.10)
P1.11: U1.P$B19 (P1.11)
P1.12: U1.P$B17 (P1.12)
P1.13: U1.P$A16 (P1.13)
P1.14: U1.P$B15 (P1.14)
P1.15: U1.P$A14 (P1.15)
P$AC5: C20.1, U1.P$AC5 (DEC3V3)
PMIC_INT: IC1.A1 (!INT), U1.P$T2 (P0.11)
PREVGH: D5.1 (K), EPD_C9.1, J1.21
PREVGL: D3.2 (A), EPD_C11.1, J1.23
RESE: J1.3, Q3.2 (S), R1_EP_DR.2
RESET: J2.6, TP_RESET\.TP, U1.P$AC13 (P0.18/RESET)
SCK: J1.13, U1.P$A12 (P0.02/AIN0)
SCL: IC1.B1 (SCL), IC2.C1 (SCL), IC3.12 (SCX), R4.1, R17.2, TP_SCL.TP, U1.P$M2 (P0.07), U3.7 (SCL)
SDA: IC1.C1 (SDA), IC2.B2 (SDA), IC3.2 (SDX), R2.1, R18.2, TP_SDA.TP, U1.P$L1 (P0.06), U3.8 (SDA)
SWDCLK: J2.4, TP_SWDCLK.TP, U1.P$AA24 (SWDCLK)
SWDIO: J2.2, TP_SWDIO.TP, U1.P$AC24 (SWDIO)
SWO: TP_SWO.TP, U1.P$AD22 (P1.00)
VBAT: C27.1, C37.1, IC1.C2 (BAT), TP_VBAT.TP, U3.2 (CELL), U3.3 (VDD)
VBUS: C21.1, C38.1, C42.1, C43.1, D2.5 (VBUS), IC1.A2 (IN), J4.A4_B9 (VBUS), J4.A9_B4 (VBUS), U1.P$AD2 (VBUS)
VREG: C23.2, C24.2, C39.1, IC1.B2 (SYS), IC9.A1 (EN), IC9.A2 (VIN_1), IC9.A3 (VIN_2), TP_VREG.TP

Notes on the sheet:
DEC4_6
DEC3
DEC1
N.C.
DEC4_6
DMG2305UX-7
LiPo Charger
DC/DC
nRF52840
Buttons
IMU
SWD
E-Paper Drive Circuit
Fuel Gauge
E-Paper Display Connector
USB C Connector and ESD Protection
Haptic Driver

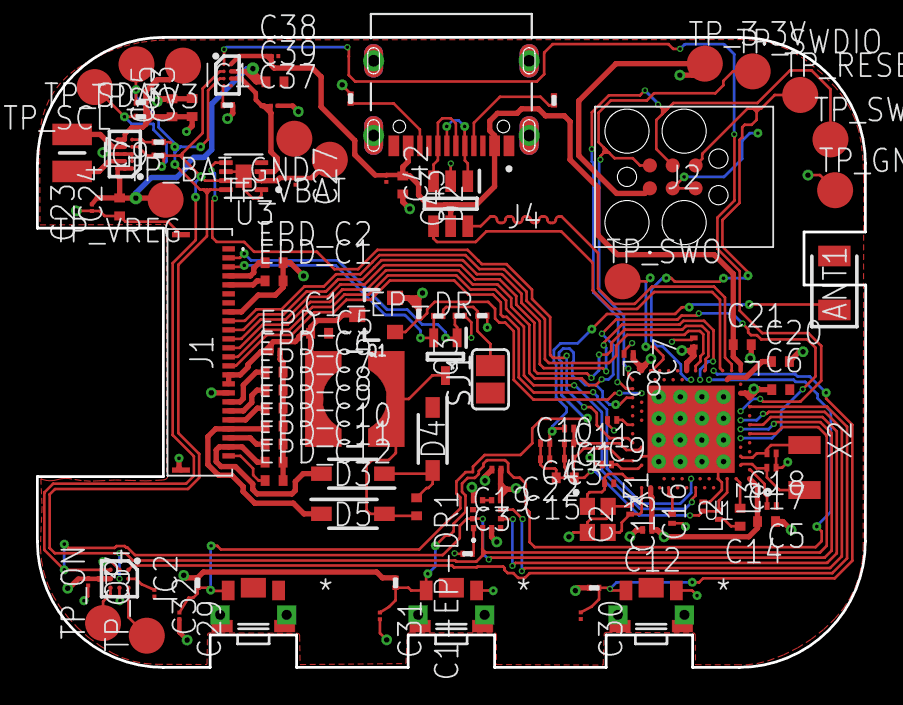
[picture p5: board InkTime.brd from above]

Board: 4 copper layers, 46.0 x 35.0 mm, 105 parts (0 on the bottom side), 70 nets.

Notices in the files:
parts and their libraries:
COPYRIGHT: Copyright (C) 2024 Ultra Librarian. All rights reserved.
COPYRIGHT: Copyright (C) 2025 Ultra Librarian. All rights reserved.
